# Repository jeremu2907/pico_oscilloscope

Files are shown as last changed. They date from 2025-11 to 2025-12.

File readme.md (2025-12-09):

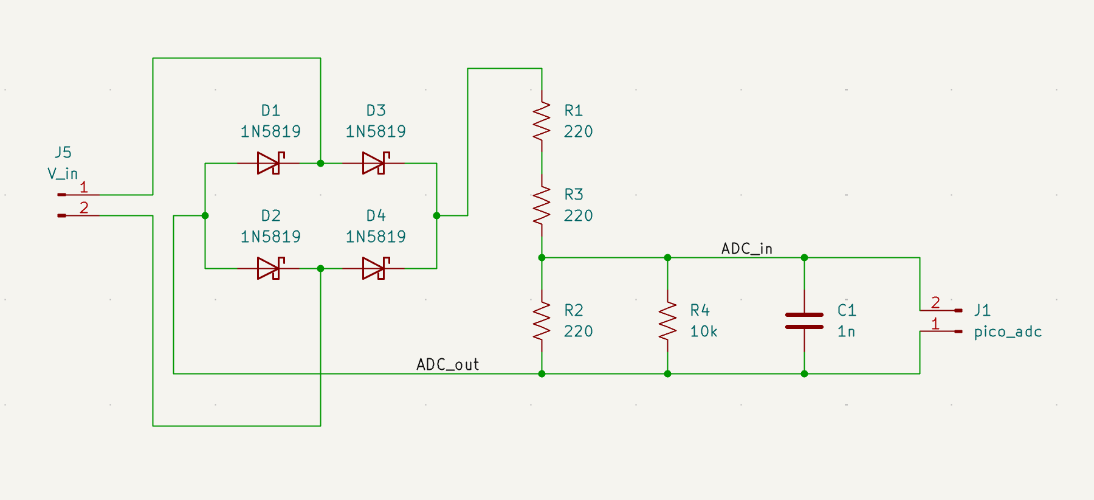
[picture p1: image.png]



https://github.com/user-attachments/assets/dc531678-6600-4c17-865a-9ecb72ba17ac

https://github.com/user-attachments/assets/cd0efd30-149d-468c-a42a-c6fa3a5c8240

https://github.com/user-attachments/assets/f2d84a0b-0583-4837-9c11-803d82c9e2e8

https://github.com/user-attachments/assets/791f4eb1-17fd-4e78-958c-5dc652bf3b7a

# Version 2

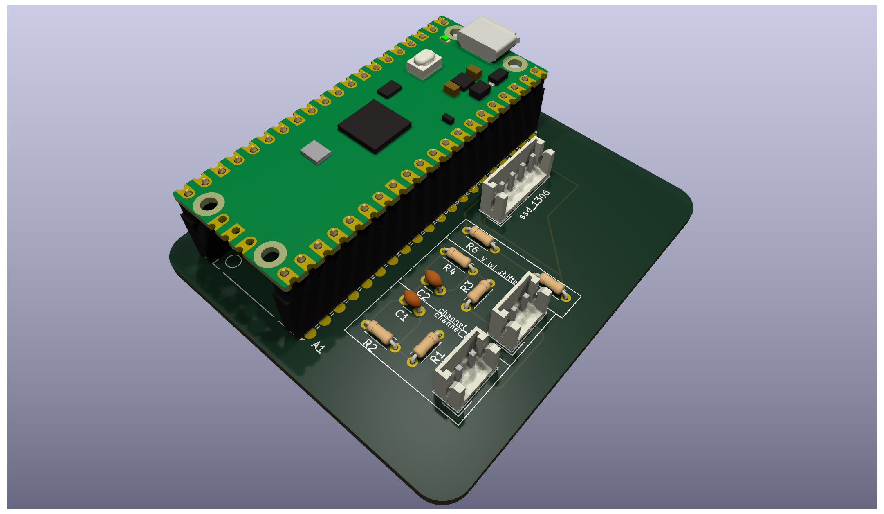
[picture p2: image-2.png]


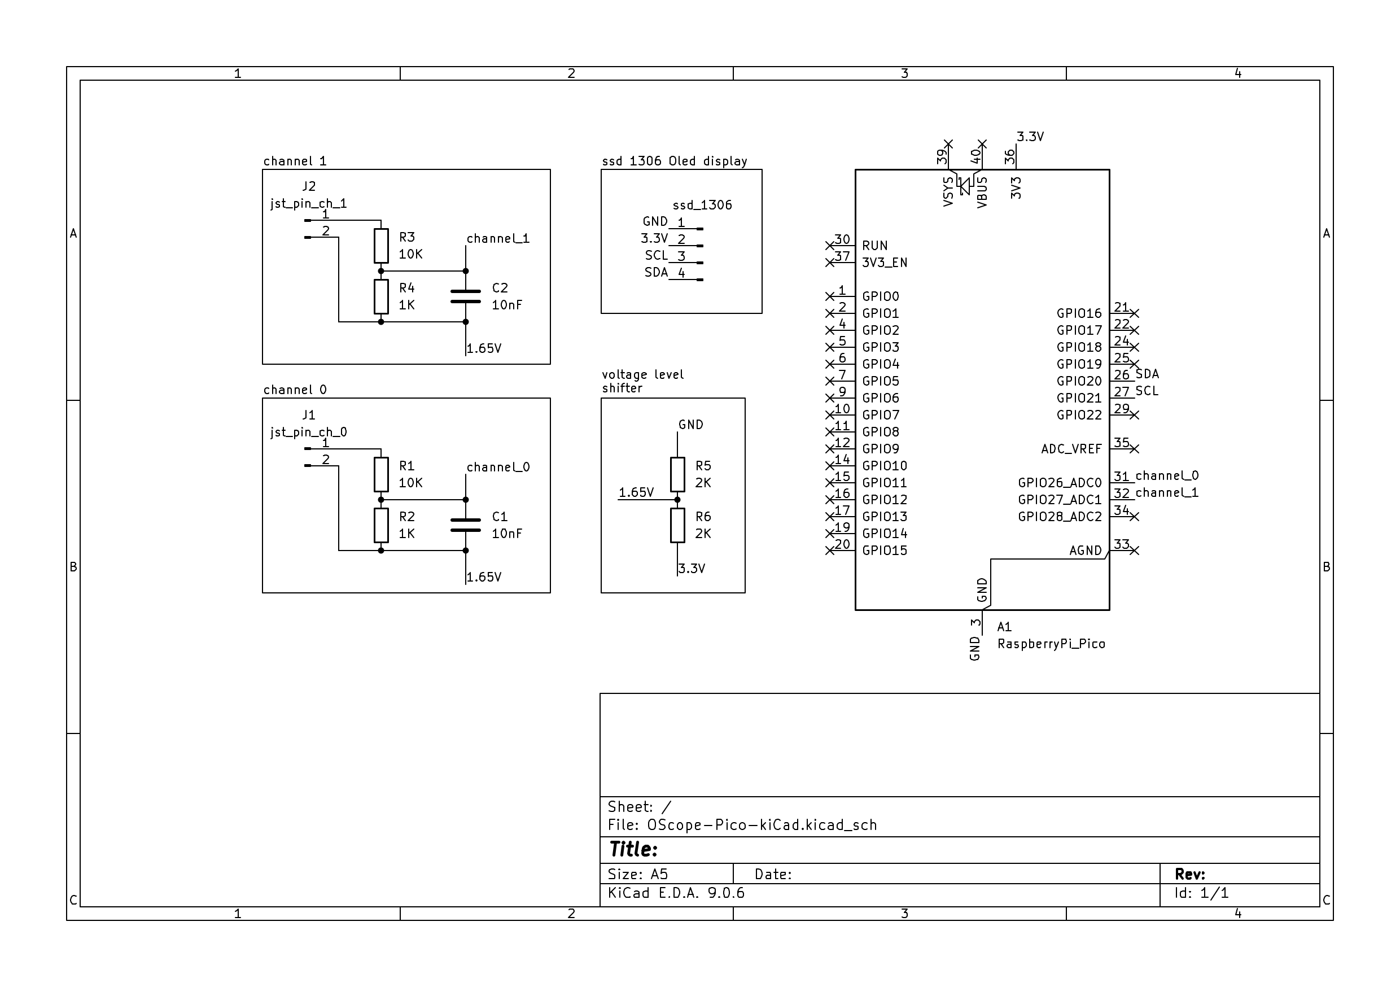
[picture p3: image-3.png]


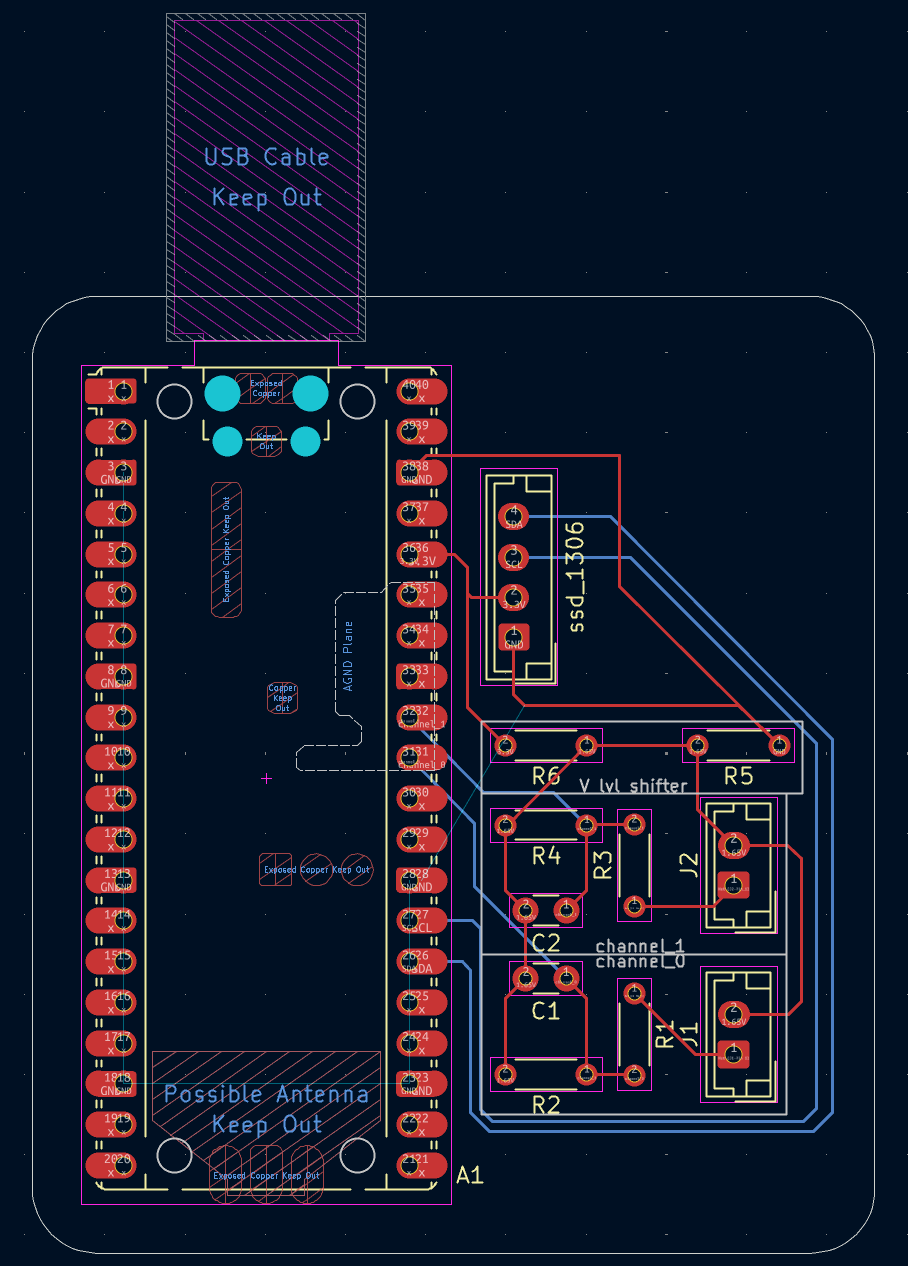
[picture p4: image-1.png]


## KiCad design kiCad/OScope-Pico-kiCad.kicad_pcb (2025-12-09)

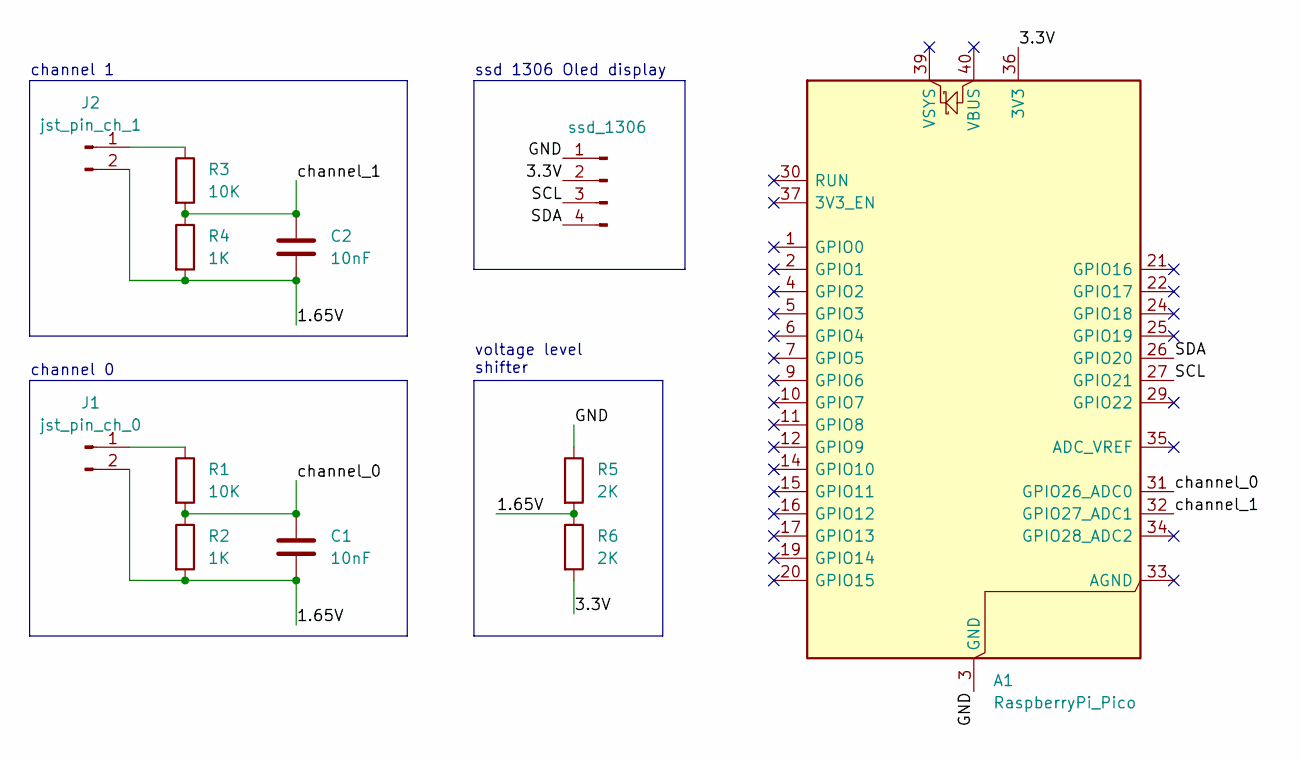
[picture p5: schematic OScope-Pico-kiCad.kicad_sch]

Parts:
A1: RaspberryPi_Pico; RaspberryPi_Pico_Common_Unspecified
C1, C2: 10nF; C_Disc_D3.0mm_W1.6mm_P2.50mm
J1: jst_pin_ch_0; JST_EH_B2B-EH-A_1x02_P2.50mm_Vertical
J2: jst_pin_ch_1; JST_EH_B2B-EH-A_1x02_P2.50mm_Vertical
R1, R3: 10K; R_Axial_DIN0204_L3.6mm_D1.6mm_P5.08mm_Horizontal
R2, R4: 1K; R_Axial_DIN0204_L3.6mm_D1.6mm_P5.08mm_Horizontal
R5, R6: 2K; R_Axial_DIN0204_L3.6mm_D1.6mm_P5.08mm_Horizontal
ssd_1306: ssd_1306; JST_EH_B4B-EH-A_1x04_P2.50mm_Vertical

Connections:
/1.65V: C1.2, C2.2, J1.2, J2.2, R2.2, R4.2, R5.2, R6.1
/3.3V: A1.36 (3V3), R6.2, ssd_1306.2
/GND: A1.3 (GND), A1.8 (GND), A1.13 (GND), A1.18 (GND), A1.23 (GND), A1.28 (GND), A1.38 (GND), R5.1, ssd_1306.1
/SCL: A1.27 (GPIO21), ssd_1306.3
/SDA: A1.26 (GPIO20), ssd_1306.4
/channel_0: A1.31 (GPIO26_ADC0), C1.1, R1.2, R2.1
/channel_1: A1.32 (GPIO27_ADC1), C2.1, R3.2, R4.1
unnamed: J1.1, R1.1
unnamed: J2.1, R3.1

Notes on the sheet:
ssd 1306 Oled display
voltage level shifter
channel 0
channel 1

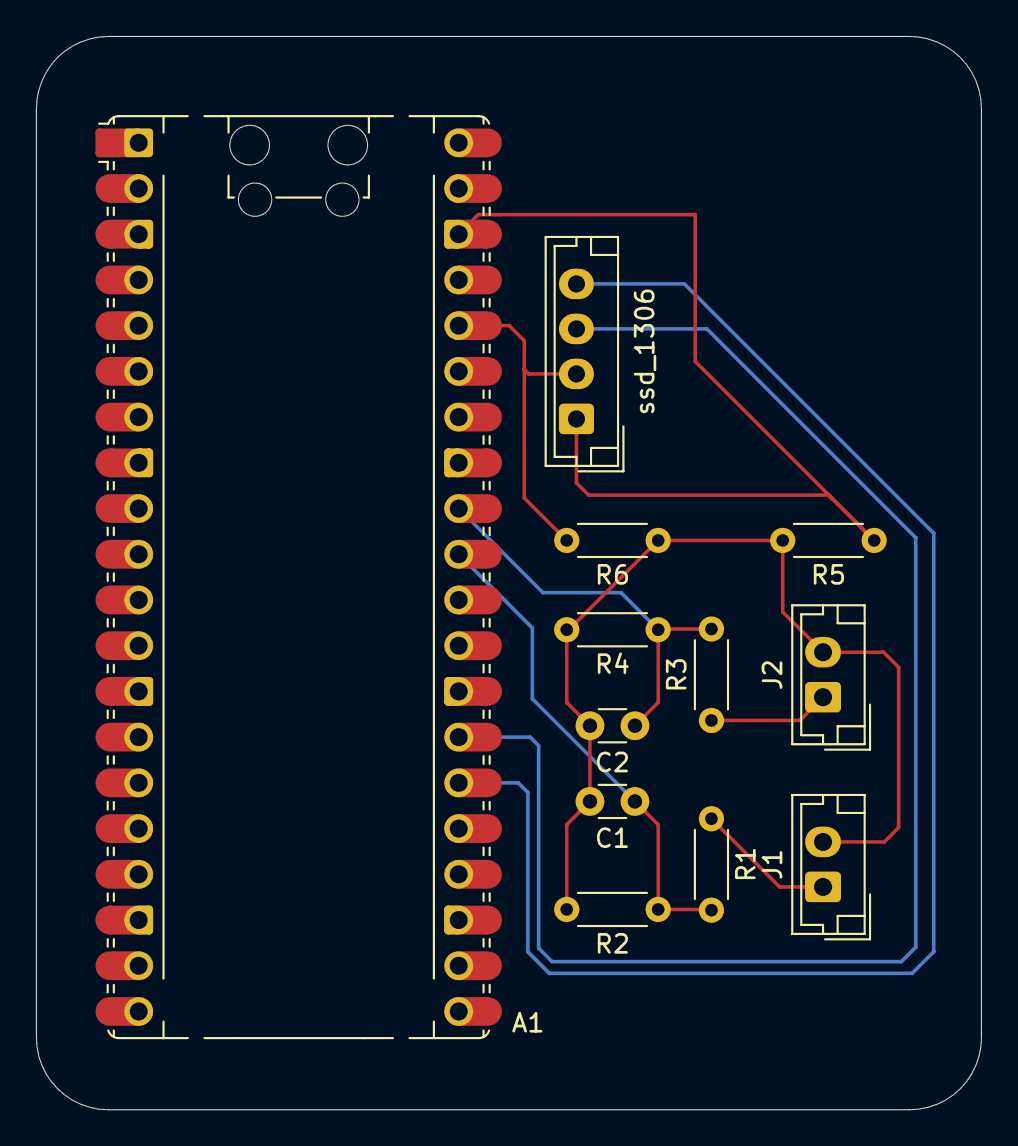
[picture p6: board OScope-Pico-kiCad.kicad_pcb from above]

Board: 2 copper layers, 52.5 x 59.6 mm, 12 parts (0 on the bottom side), 9 nets.

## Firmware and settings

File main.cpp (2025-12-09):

#if IS_WIRELESS
#include "pico/cyw43_arch.h"
#endif

#include "pico/time.h"
#include "math.h"

#include "Macros.hpp"

#include "adc/Input.hpp"
#include "gpio/Base.hpp"
#include "i2c/Ssd1306.h"
#include "i2c/Font8x8.h"

int main()
{
    constexpr float VOLTAGE_LEVEL_BIAS = 1.509f;
    constexpr float FRONTEND_VOLTAGE_DIVIDER_RATIO = (1e3 + 10e3) / 1e3;
    constexpr float MINIMUN_VOLTAGE_THRESHOLD = 0.0075;
    constexpr float REVERSED_POLARITY_VOLTAGE_BIAS = 0.0;
    constexpr uint64_t MS_BETWEEN_SSD_1306_UPDATE = 100;

#if IS_WIRELESS
    if (cyw43_arch_init())
    {
        printf("Wi-Fi init failed!\n");
        return 1;
    }
#endif

    stdio_init_all();
    Gpio::Base::onboardLedOn();

    uint64_t currentTimeMs = to_ms_since_boot(get_absolute_time());
    Adc::Input gp28A2(28, Adc::Input::GPIO_28_ADC);
    Adc::Input gp27A1(27, Adc::Input::GPIO_27_ADC);
    gpio_pull_down(28);
    gpio_pull_down(27);
    I2c::Ssd1306 oled(20, 21, i2c0);

    float vChannel0 = 0.0;
    float vChannel1 = 0.0;

    gp28A2.installCallback(
        [&currentTimeMs, &oled, &vChannel0](float voltage)
        {
            float unbiasedVoltage = voltage - VOLTAGE_LEVEL_BIAS;
            vChannel0 = FRONTEND_VOLTAGE_DIVIDER_RATIO * unbiasedVoltage;
            if (abs(unbiasedVoltage) < MINIMUN_VOLTAGE_THRESHOLD)
            {
                vChannel0 = 0.0;
            }
            else if(vChannel0 < 0.0)
            {
                vChannel0 -= REVERSED_POLARITY_VOLTAGE_BIAS;
            }

            printf("ch_0 %f\n", vChannel0);
        });

    gp27A1.installCallback(
        [&currentTimeMs, &oled, &vChannel1](float voltage)
        {
            float unbiasedVoltage = voltage - VOLTAGE_LEVEL_BIAS;
            vChannel1 = FRONTEND_VOLTAGE_DIVIDER_RATIO * unbiasedVoltage;
            if (abs(unbiasedVoltage) < MINIMUN_VOLTAGE_THRESHOLD)
            {
                vChannel1 = 0.0;
            }
            else if (vChannel1 < 0.0)
            {
                vChannel1 -= REVERSED_POLARITY_VOLTAGE_BIAS;
            }

            printf("ch_1 %f\n", vChannel1);
        });

    MAIN_LOOP_START
    Adc::Input::runLoop();
    uint64_t now = to_ms_since_boot(get_absolute_time());
    if (now - currentTimeMs > MS_BETWEEN_SSD_1306_UPDATE)
    {
        std::string vChannel0Str = std::to_string(vChannel0);
        std::string vChannel1Str = std::to_string(vChannel1);
        std::string paddingChannel0 = ((vChannel0 < 0) ? "" : " ");
        std::string paddingChannel1 = ((vChannel1 < 0) ? "" : " ");
        std::string s = (std::string("\n") +
                        "ch_0:" + paddingChannel0 + vChannel0Str +
                        "\n\n" +
                        "ch_1:" + paddingChannel1 + vChannel1Str);
        oled.clearData();
        oled.setData(s);
        oled.writeData();
        currentTimeMs = now;
    }
    MAIN_LOOP_END
}

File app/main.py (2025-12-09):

import serial
import matplotlib.pyplot as plt
import matplotlib.animation as animation
from collections import deque
import time

USB_PORT = '/dev/cu.usbmodem1101'
BAUDRATE = 115200
GUI_WINDOW_SECONDS = 20
UPDATE_INTERVAL_MS = 50
MAX_POINTS = 10000

times_ch0 = deque(maxlen=MAX_POINTS)
times_ch1 = deque(maxlen=MAX_POINTS)
volt_ch0 = deque(maxlen=MAX_POINTS)
volt_ch1 = deque(maxlen=MAX_POINTS)
start_time = time.time()

plt.style.use('dark_background')
fig, ax = plt.subplots()
channel_0_line, = ax.plot([], [], color='yellow', lw=1.8, label='channel 0')
channel_1_line, = ax.plot([], [], color='red', lw=1.8, label='channel 1')
ax.legend()

auto_scroll = True

def toggle_live(event):
    global auto_scroll
    if event.key == ' ':
        auto_scroll = not auto_scroll

fig.canvas.mpl_connect('key_press_event', toggle_live)

def try_connect():
    try:
        return serial.Serial(USB_PORT, BAUDRATE, timeout=0.5)
    except:
        return None

ser = try_connect()

def update(frame):
    global ser

    if ser is None or not ser.is_open:
        ser = try_connect()
        return channel_0_line, channel_1_line

    try:
        while ser.in_waiting:
            line = ser.readline().decode('utf-8').strip()
            parts = line.split()
            if len(parts) != 2:
                continue
            ch = parts[0]
            try:
                v = float(parts[1])
            except:
                continue
            t = time.time() - start_time
            if ch == 'ch_0':
                times_ch0.append(t)
                volt_ch0.append(v)
            elif ch == 'ch_1':
                times_ch1.append(t)
                volt_ch1.append(v)
    except:
        try:
            ser.close()
        except:
            pass
        ser = None
        return channel_0_line, channel_1_line

    channel_0_line.set_data(times_ch0, volt_ch0)
    channel_1_line.set_data(times_ch1, volt_ch1)

    if auto_scroll:
        last_t = 0
        if times_ch0:
            last_t = max(last_t, times_ch0[-1])
        if times_ch1:
            last_t = max(last_t, times_ch1[-1])
        ax.set_xlim(last_t - GUI_WINDOW_SECONDS, last_t)

        vals = []
        vals.extend(volt_ch0)
        vals.extend(volt_ch1)
        if vals:
            vmin, vmax = min(vals), max(vals)
            pad = (vmax - vmin) * 0.2 if vmax != vmin else 0.05
            ax.set_ylim(vmin - pad, vmax + pad)

    return channel_0_line, channel_1_line

ani = animation.FuncAnimation(fig, update, interval=UPDATE_INTERVAL_MS, blit=False, save_count=MAX_POINTS)
plt.show()

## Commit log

2025-12-06 ki cad
    [OScope-Pico-kiCad.kicad_pcb, OScope-Pico-kiCad.kicad_sch]
2025-12-06 removed magic number and calibrated
